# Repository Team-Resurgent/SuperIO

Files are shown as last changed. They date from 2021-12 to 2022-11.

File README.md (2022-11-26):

SuperIO

This is a Work In Progress version of https://github.com/XboxDev/serial-usb-adapter.

I started this so that mnanufacture would be cheaper having components on one side.

There maybe a mistake on the BOM / crystal

Ultimately I would like to merge with the xenium chip / add maybe other useful features.

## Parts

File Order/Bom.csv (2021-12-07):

Comment | Designator | Footprint | LCSC Part #
10k | R1 R4 | 0603-RES | C269701
14.31818 oscillator | Q1 | SMD5032-4P | C387229
10uF | C5 | 0603-CAP | C96446
47pF | C4 | 0603-CAP | C1671
100nF | C1 C2 C3 | 0603-CAP | C191538
680 | R2 R3 R5 | 0603-RES | C23228
475900001 | J2 | 475900001 | C136001
Blue | RX | CHIP-LED0603 | C99290
CP2102 | IC1 | MLP28 | C6568
Green | TX | CHIP-LED0603 | C72043
LPC47M192 | U1 | QFP128
PTCSMD | F1 | PTC-1206 | C99561
White | PWR | CHIP-LED0603 | C158100

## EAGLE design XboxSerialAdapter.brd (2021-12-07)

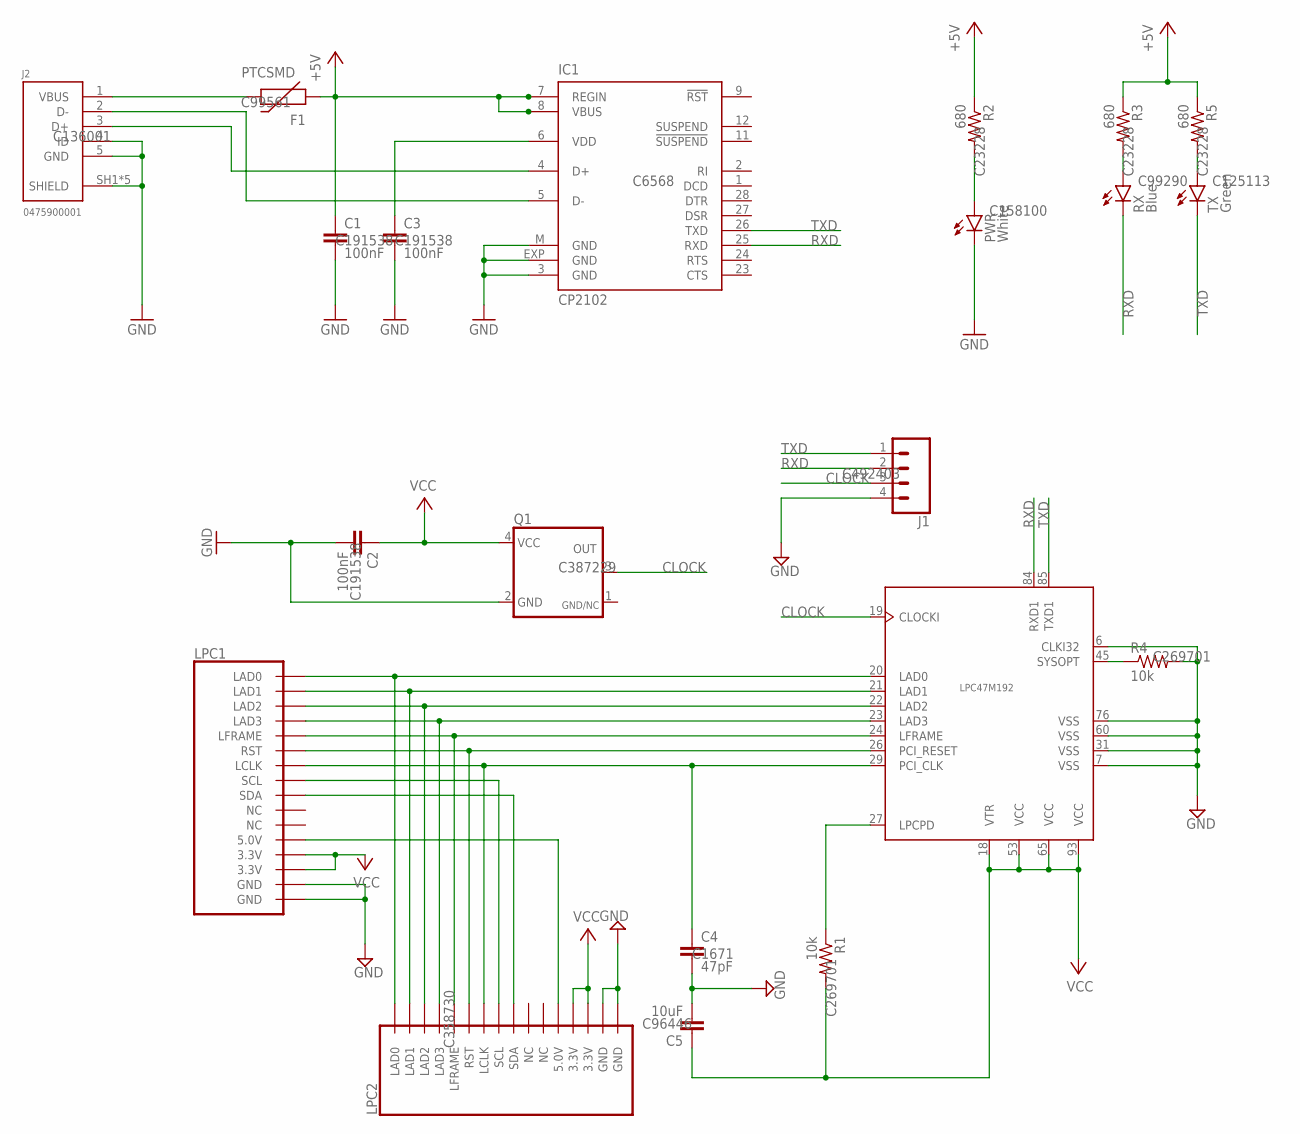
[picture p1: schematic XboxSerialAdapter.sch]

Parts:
C1, C2, C3: 100nF; 0603-CAP; LCSC_PART C191538
C4: 47pF; 0603-CAP; LCSC_PART C1671
C5: 10uF; 0603-CAP; LCSC_PART C96446
F1: PTCSMD; PTC-1206; LCSC_PART C99561
IC1: CP2102; MLP28; LCSC_PART C6568
J1: CONN_04; 1X04; LCSC_PART C492403
J2: 0475900001; LCSC_PART C136001
LPC1: LPC_HEADERLPC_FEMALE; HDRVR16W64P254_2X8_1524X508X254B; LCSC_PART C492425
LPC2: LPC_HEADERLPC_FEMALE; HDRVR16W64P254_2X8_1524X508X254B; LCSC_PART C358730
PWR: White; CHIP-LED0603; LCSC_PART C158100
Q1: SCTF_C3872291; SCTF_C387229; LCSC_PART C387229
R1, R4: 10k; 0603-RES; LCSC_PART C269701
R2, R3, R5: 680; 0603-RES; LCSC_PART C23228
RX: Blue; CHIP-LED0603; LCSC_PART C99290
TX: Green; CHIP-LED0603; LCSC_PART C125113
U1: LPC47M192; QFP128

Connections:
5.0V: LPC1.6 (5.0V), LPC2.6 (5.0V)
+5V: C1.1, F1.1, IC1.7 (REGIN), IC1.8 (VBUS), R2.1, R3.1, R5.1
CLOCK: J1.3, Q1.3 (OUT), U1.19 (CLOCKI)
D+: IC1.4 (D+), J2.3 (D+)
D-: IC1.5 (D-), J2.2 (D-)
GND: C1.2, C2.2, C3.2, C4.2, C5.2, IC1.3 (GND), IC1.EXP (GND), IC1.M (GND), J1.4, J2.4 (ID), J2.5 (GND), J2.SH1 (SHIELD), J2.SH2 (SHIELD), J2.SH3 (SHIELD), J2.SH4 (SHIELD), J2.SH5 (SHIELD), LPC1.2 (GND), LPC1.12 (GND), LPC2.2 (GND), LPC2.12 (GND), PWR.C, Q1.2 (GND), R4.2, U1.6 (CLKI32), U1.7 (VSS), U1.31 (VSS), U1.60 (VSS), U1.76 (VSS)
GND/NC: Q1.1 (GND/NC)
LAD0: LPC1.11 (LAD0), LPC2.11 (LAD0), U1.20 (LAD0)
LAD1: LPC1.10 (LAD1), LPC2.10 (LAD1), U1.21 (LAD1)
LAD2: LPC1.8 (LAD2), LPC2.8 (LAD2), U1.22 (LAD2)
LAD3: LPC1.7 (LAD3), LPC2.7 (LAD3), U1.23 (LAD3)
LCLK: C4.1, LPC1.1 (LCLK), LPC2.1 (LCLK), U1.29 (PCI_CLK)
LFRAME: LPC1.3 (LFRAME), LPC2.3 (LFRAME), U1.24 (LFRAME)
unnamed: R4.1, U1.45 (SYSOPT)
unnamed: R5.2, TX.A
unnamed: R3.2, RX.A
unnamed: C3.1, IC1.6 (VDD)
unnamed: R1.1, U1.27 (LPCPD)
unnamed: PWR.A, R2.2
RST: LPC1.5 (RST), LPC2.5 (RST), U1.26 (PCI_RESET)
RXD: IC1.25 (RXD), J1.2, RX.C, U1.84 (RXD1)
SCL: LPC1.13 (SCL), LPC2.13 (SCL)
SDA: LPC1.14 (SDA), LPC2.14 (SDA)
TXD: IC1.26 (TXD), J1.1, TX.C, U1.85 (TXD1)
VBUS: F1.2, J2.1 (VBUS)
VCC: C2.1, C5.1, LPC1.9 (3.3V), LPC1.15 (3.3V), LPC2.9 (3.3V), LPC2.15 (3.3V), Q1.4 (VCC), R1.2, U1.18 (VTR), U1.53 (VCC), U1.65 (VCC), U1.93 (VCC)

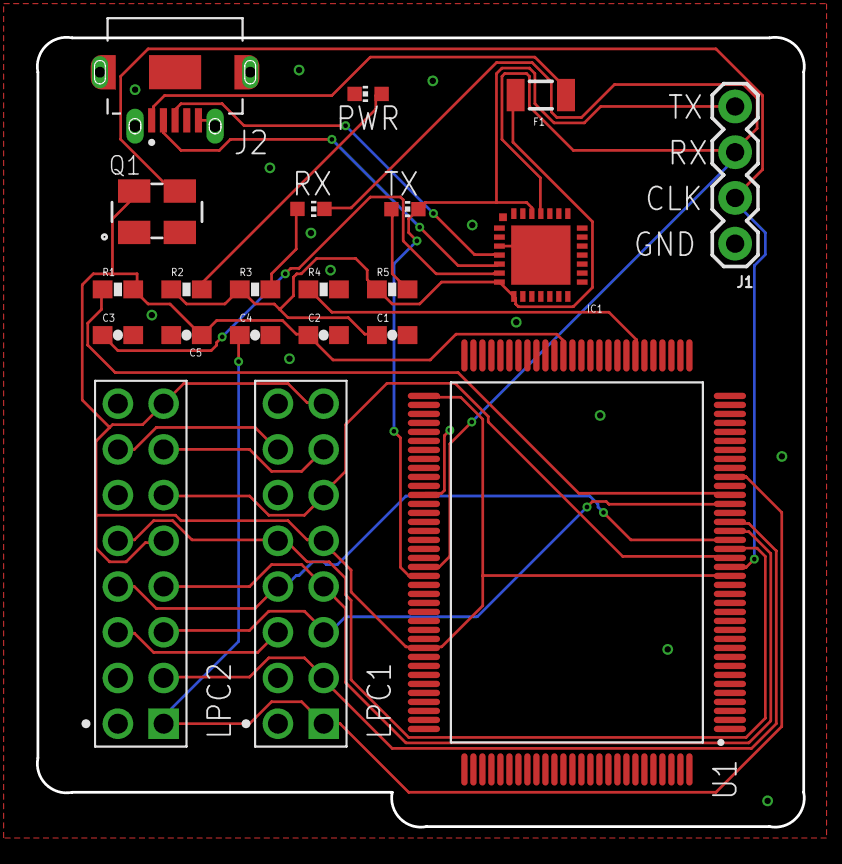
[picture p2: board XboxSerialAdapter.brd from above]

Board: 2 copper layers, 42.6 x 43.9 mm, 21 parts (0 on the bottom side), 25 nets.

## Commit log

2021-12-07 Update: added files
    [Bom.csv, XboxSerialAdapter.brd, XboxSerialAdapter.sch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]
2021-12-07 Update: crystal
    [XboxSerialAdapter.brd, XboxSerialAdapter.sch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]
2021-12-07 Update: files
    [Bom.csv, XboxSerialAdapter.brd, XboxSerialAdapter.sch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]

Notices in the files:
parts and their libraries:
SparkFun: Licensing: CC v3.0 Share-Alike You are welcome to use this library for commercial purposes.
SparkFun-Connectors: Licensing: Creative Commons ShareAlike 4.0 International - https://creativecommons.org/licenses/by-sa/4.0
